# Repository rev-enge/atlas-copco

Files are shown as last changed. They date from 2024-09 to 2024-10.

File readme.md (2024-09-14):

# Atlas Copco controller for  Xas186 Xas196 compressor 

Reverse engineered (parts) of this controller that guards the miscellaneous sensors of the diesel engine.

The controller has 4 dipswitches to control optional input sensors such as "fuel low level" and "coolant low level".

The label says that the program CLB733 is inside the controller.

# Table of contents

* 1089935597 => [Controller for XAS186 / XAS196](1089935597/readme.md)

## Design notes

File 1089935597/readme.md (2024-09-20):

# Identification of the board

Type: 1089935597

Manufacturers number: 35597.0

Program No: CLB733

DC Volts: 12V

Picture of the device:

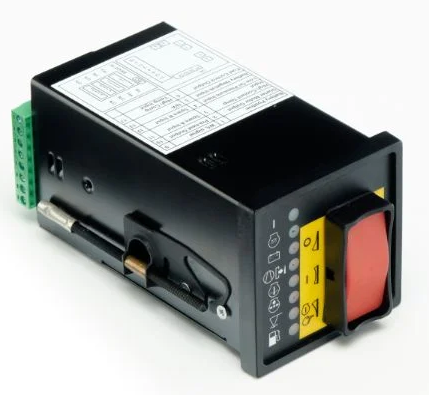
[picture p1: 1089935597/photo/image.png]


# Description

This board contains 3 output relays to control:

* The fuel control (on/off).
* Pre-heating.
* Sngine start.

This board contains 8 status leds at the front:

* H1 Green Fuel ON
* H2 Green Preheat (option)
* H3 Red   Charge indication
* H4 Red   Compressor outlet temperature
* H5 Red   Engine oil temperature
* H6 Red   Engine oli pressure
* H7 Red   Low coolant
* H8 Red   Low fuel

When an error is detected, the corresponding led lights up and you must switch of the unit to reset it (after fixing the cause of it).

# Repair hints

[Found issues in the past](repairs/readme.md)

# Utilities used to create the drawings

The schematic diagram is made with KiCad 6.0.11

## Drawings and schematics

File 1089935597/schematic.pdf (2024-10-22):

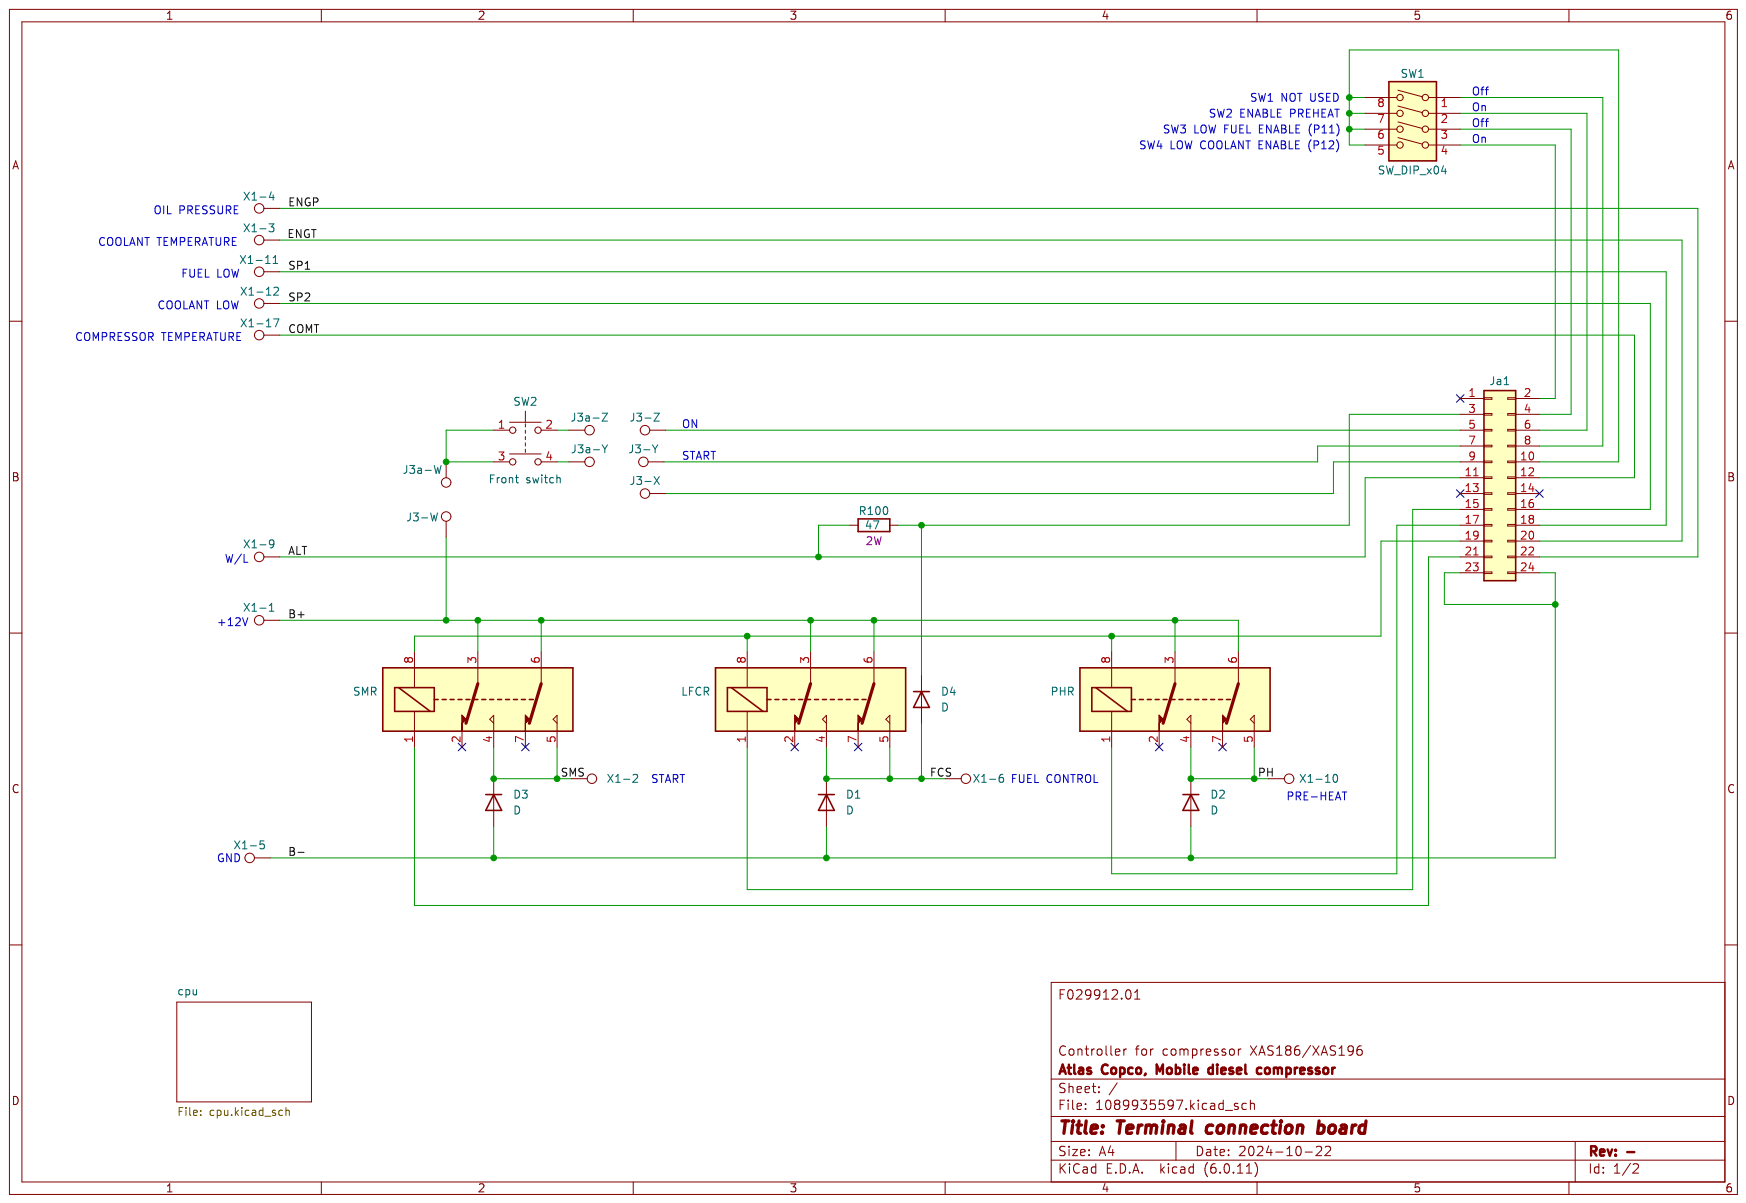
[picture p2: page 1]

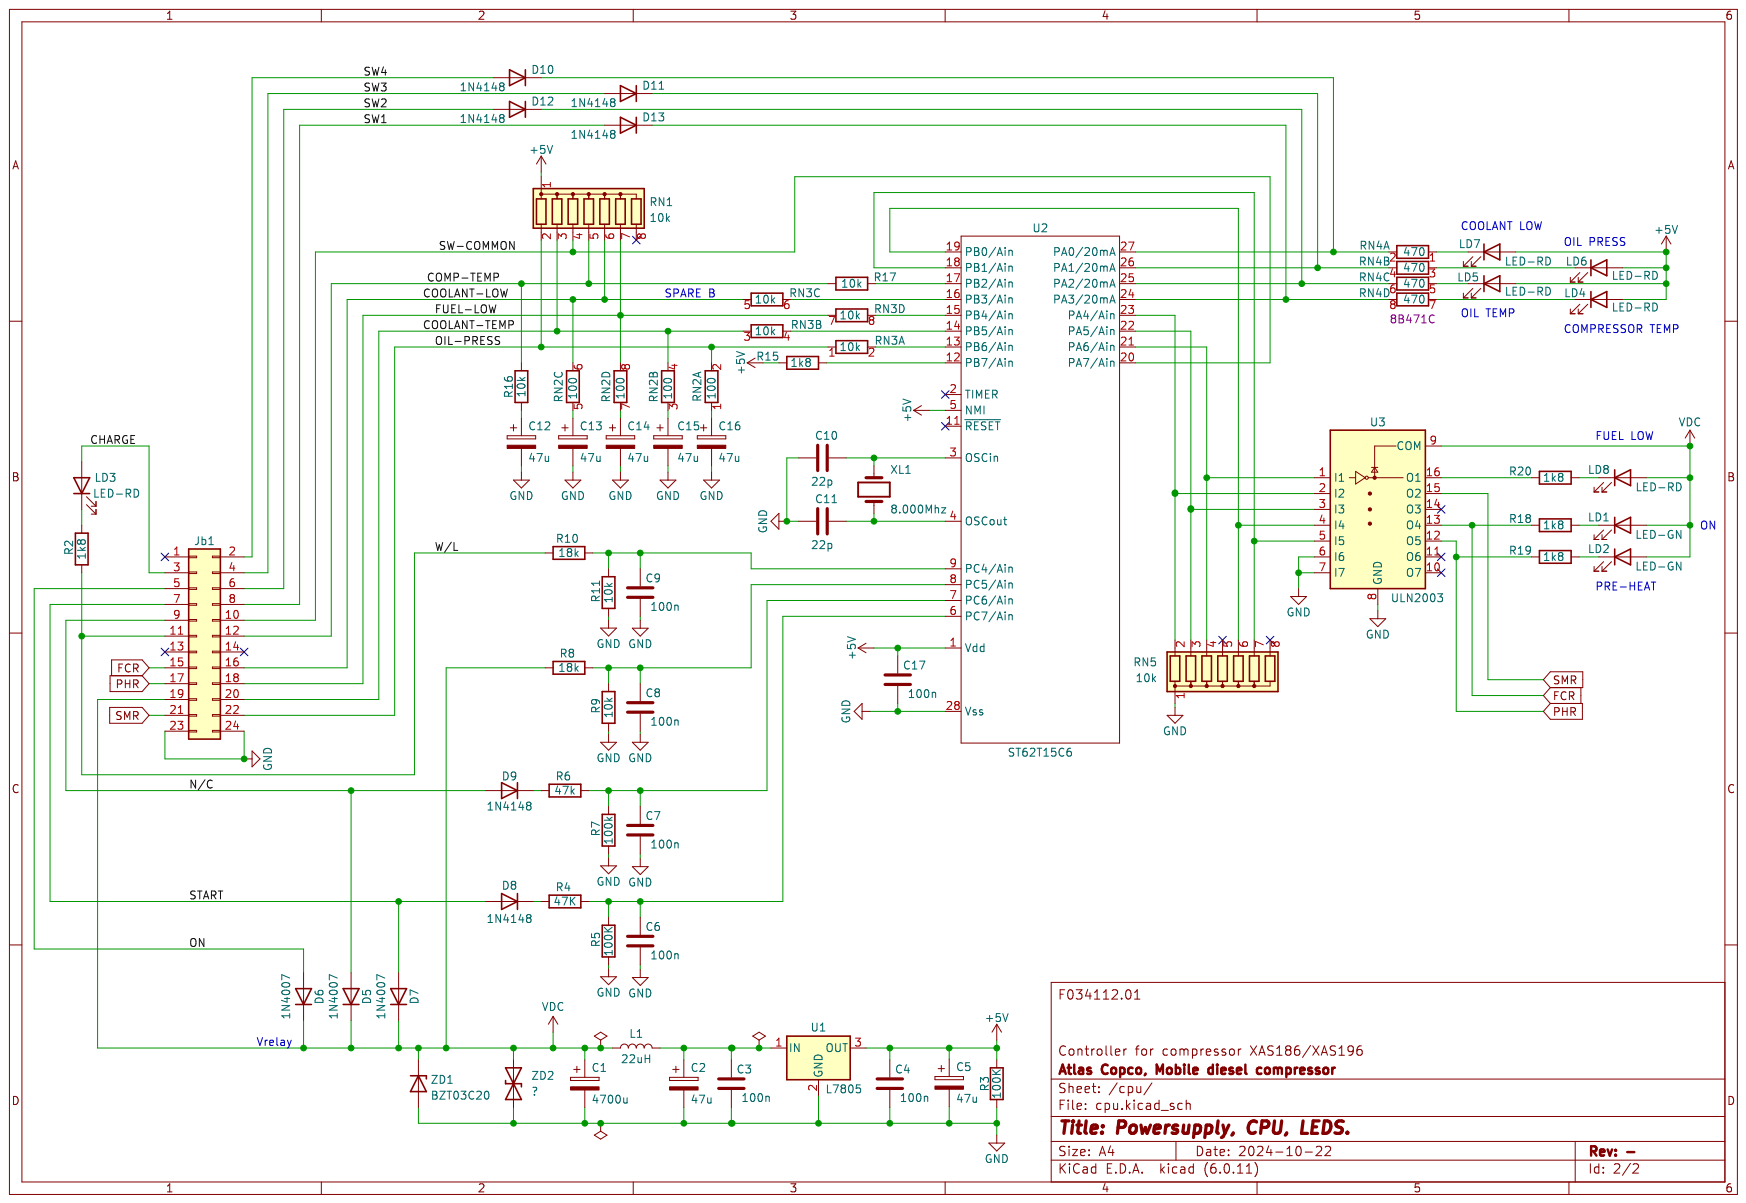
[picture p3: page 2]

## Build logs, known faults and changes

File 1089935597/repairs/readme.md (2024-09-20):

# Repairs done.

I repaired 2 of these controllers now.

## Sympthom: Device directly shows one or more RED failure leds and does nothing any more.

There was a broken trace between pion 13 of the CPU and RN3-2.
This crack was not visible because it was underneath the white silkscreen.

See the read circle here:

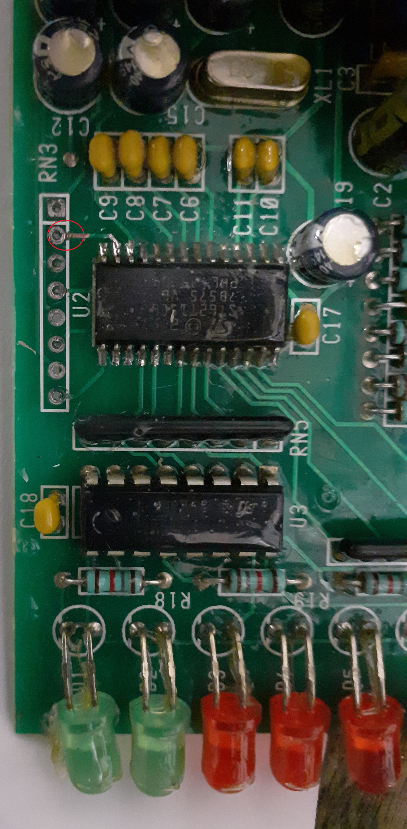
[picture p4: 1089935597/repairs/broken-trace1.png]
pcb crack


## Sympthom: SW2 not working / pre-heat led always off.

There was a broken trace between pin 25 of the CPU and the adjacent RN4-4 pin.
This crack was not visible because it was underneath the white silkscreen.
A similar problem as the first case.

So it looks like the boards are notorios for disconnected traces very near to the RN resistor packs?

### Back to main page [main](../../readme.md)

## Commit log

2024-09-14 Connection/terminal board schematic/PCB.
    [1089935597.kicad_pcb, 1089935597.kicad_sch]
2024-09-15 Add filtering around CPU and lots of other wires.
    [1089935597.kicad_sch, cpu.kicad_sch]
2024-09-16 Add last bits of the schematic. Some connector pins need to be drawn.
    [1089935597.kicad_sch, cpu.kicad_sch]
2024-09-17 Finalize the complete schematic.
    [1089935597.kicad_sch, cpu.kicad_sch]
2024-09-20 Fix pin on CPU and add legend to switches and leds.
    [1089935597.kicad_sch, cpu.kicad_sch]
2024-09-20 Add picture of the device.
2024-10-22 Small text corrections + default switch position.
    [1089935597.kicad_sch, cpu.kicad_sch]
